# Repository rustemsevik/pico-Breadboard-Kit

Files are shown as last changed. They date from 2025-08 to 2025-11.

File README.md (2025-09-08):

# Pico Breadboard Kit

This is a Raspberry Pi Pico breadboard kit designed for students to learn and experiment with basic electronics and microcontroller programming.

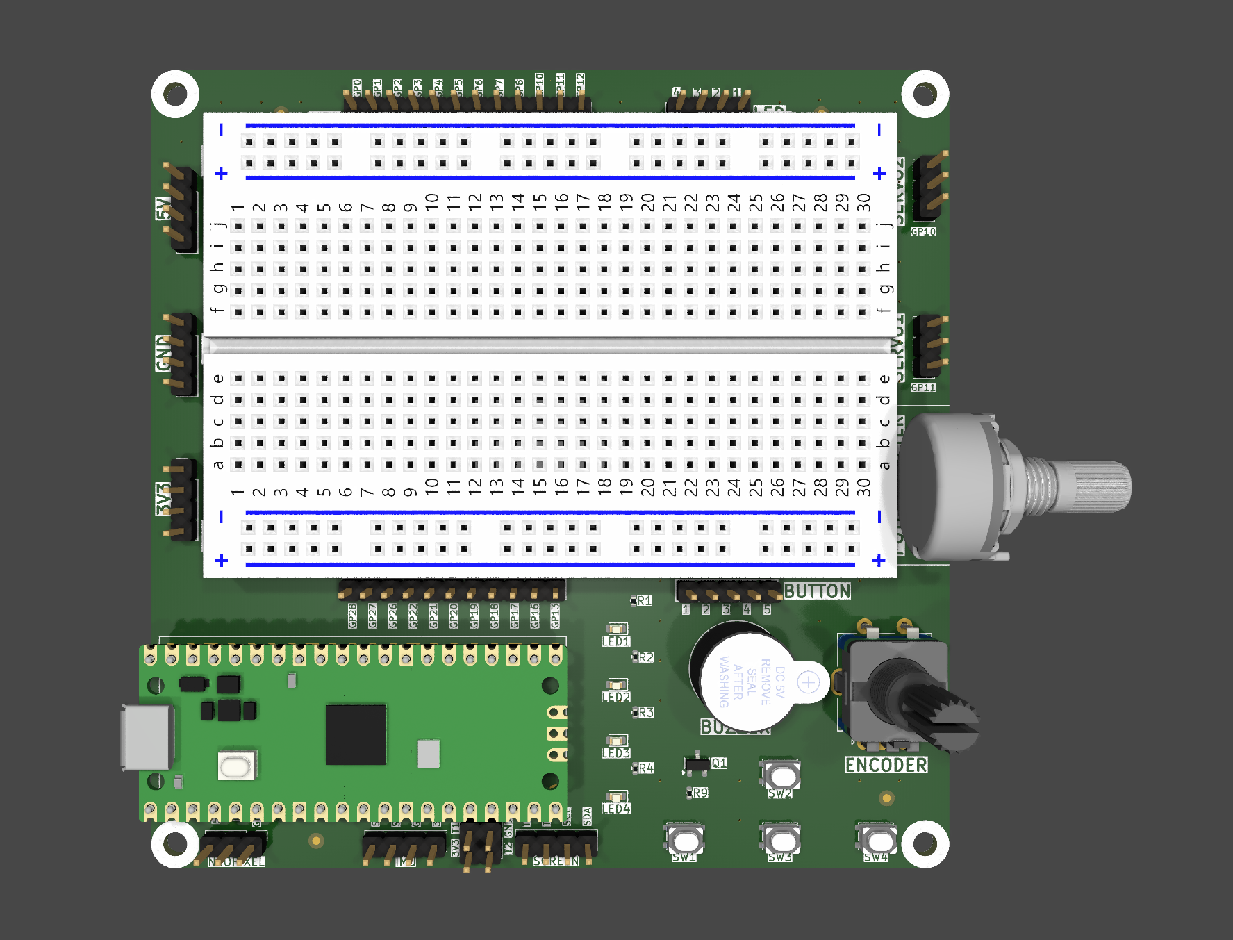
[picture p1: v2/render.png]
Pico Breadboard


## Features

- **Raspberry Pi Pico** with full GPIO breakout  
- **Four tactile buttons** connected to GPIOs  
- **Four LEDs** with current-limiting resistors  
- **Buzzer** controlled via transistor switch  
- **Rotary encoder with push switch** for interactive input  
- **Potentiometer** connected to ADC input  
- **Headers for external 3.3V and 5V power**  
- **Dedicated I2C connector for screen (SCL/SDA)**  
- **Connector for MPU6050 (I2C accelerometer/gyroscope)**  
- **Servo motor headers (2x) with GPIO control**  
- **Neopixel header** for addressable LED strips  
- Mounting holes for mechanical stability  
- All components are laid out to be easily accessible on a standard breadboard.

## Getting Started

1. Insert the Raspberry Pi Pico into the breadboard.  
2. Connect power via USB.  
3. Upload your code using Thonny or the Pico SDK.  
4. Use the built-in components (buttons, LEDs, buzzer, potentiometer, rotary encoder, servos) to test your logic.  
5. Connect external devices (screen, MPU6050, Neopixel) via the dedicated headers.  

## Schematic

See the included [`v2/pico-breadboard.pdf`](v2/pico-breadboard.pdf) for the detailed wiring.

---

This kit is ideal for beginner to intermediate-level microcontroller projects, robotics experiments, and educational settings.

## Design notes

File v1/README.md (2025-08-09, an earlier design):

# Pico Breadboard Kit

This is a simple Raspberry Pi Pico breadboard kit designed for students to learn and experiment with basic electronics and microcontroller programming.

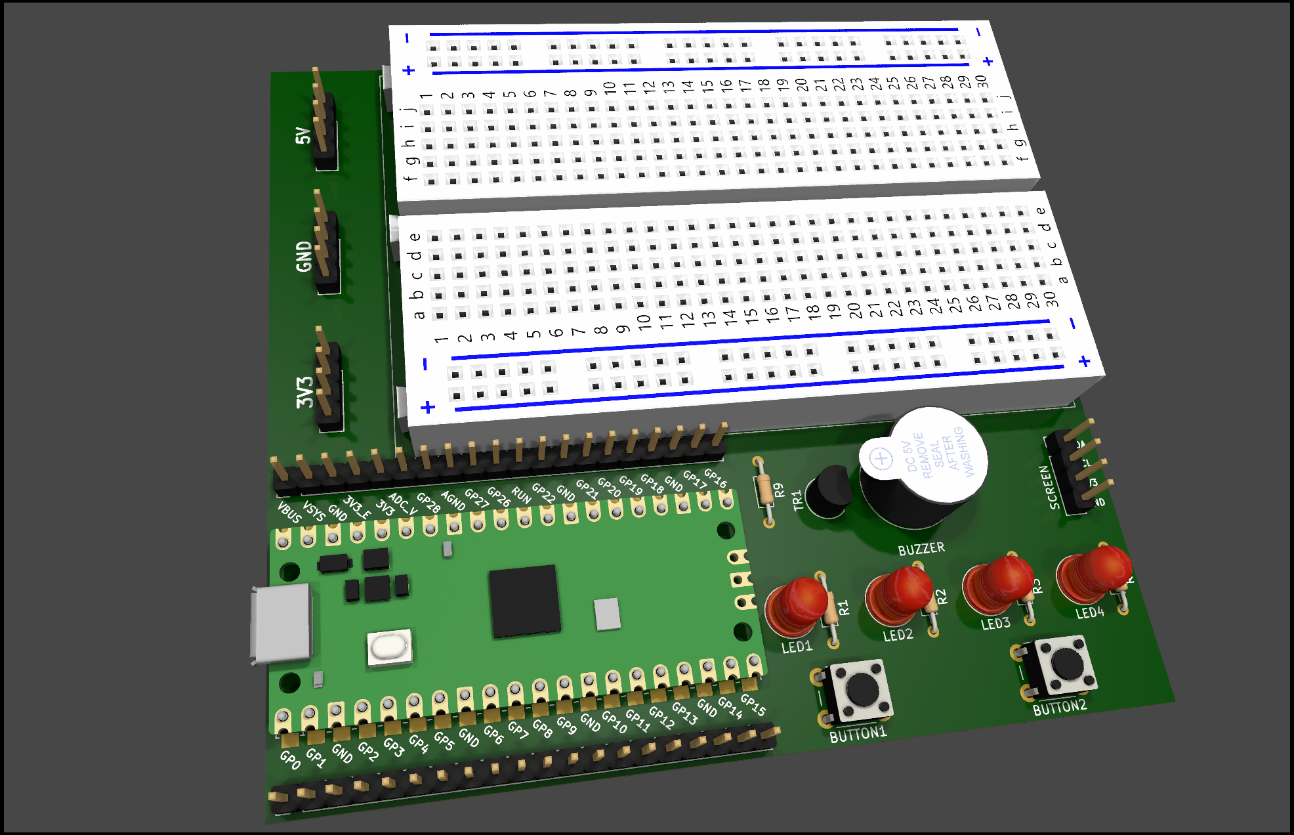
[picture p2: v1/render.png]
Pico Breadboard


## Features

- **Raspberry Pi Pico** with full GPIO breakout
- **Two tactile buttons** connected to GPIOs
- **Four LEDs** with current-limiting resistors
- **Buzzer** controlled via transistor switch
- **Headers for external 3.3V and 5V power**
- **Dedicated I2C connector for screen (SCL/SDA)**
- All components are laid out to be easily accessible on a standard breadboard.

## Getting Started

1. Insert the Raspberry Pi Pico into the breadboard.
2. Connect power via USB.
3. Upload your code using Thonny or the Pico SDK.
4. Use the built-in components (buttons, LEDs, buzzer) to test your logic.

## Schematic

See the included `schematic.pdf` for the detailed wiring.

---

This kit is ideal for beginner-level microcontroller projects and educational settings.

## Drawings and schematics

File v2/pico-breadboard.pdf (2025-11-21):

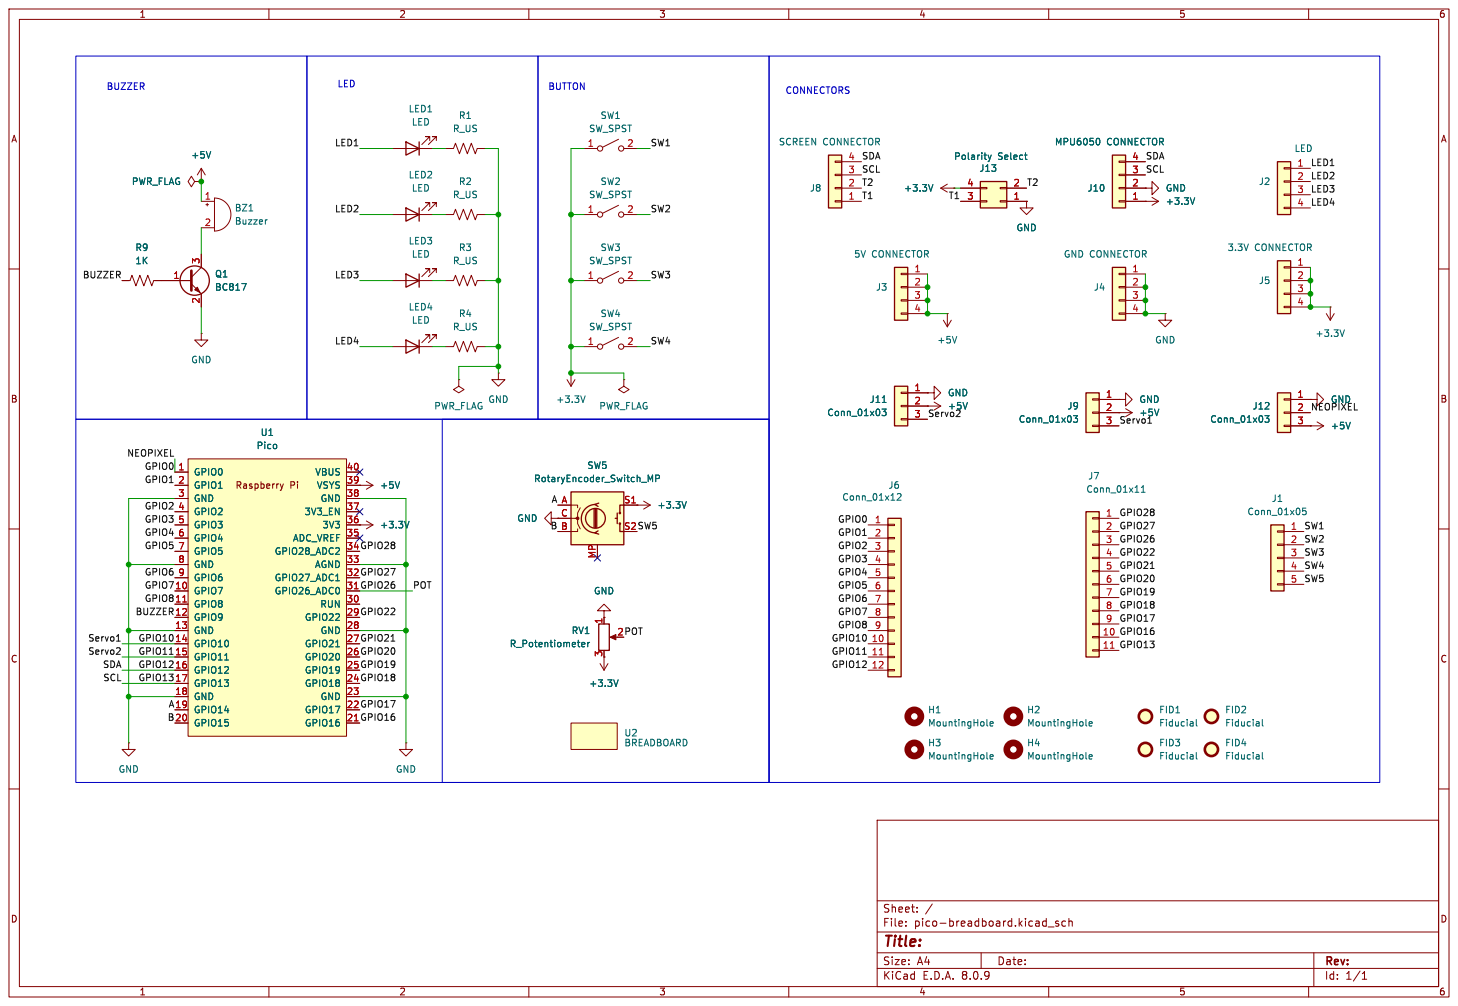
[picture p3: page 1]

3 U1 Pico GPIO0 1 GPIO7 10 GPIO8 11 GPIO9 12 GND 13 GPIO10 14 GPIO11 15 GPIO12 16 GPIO13 17 GND 18 GPIO14 19 GPIO1 2 GPIO15 20 GPIO16 21 GPIO17 22 GND 23 GPIO18 24 GPIO19 25 GPIO20 26 GPIO21 27 GND 28 GPIO22 29 GND 3 RUN 30 GPIO26_ADC0 31 GPIO27_ADC1 32 AGND 33 GPIO28_ADC2 34 ADC_VREF 35

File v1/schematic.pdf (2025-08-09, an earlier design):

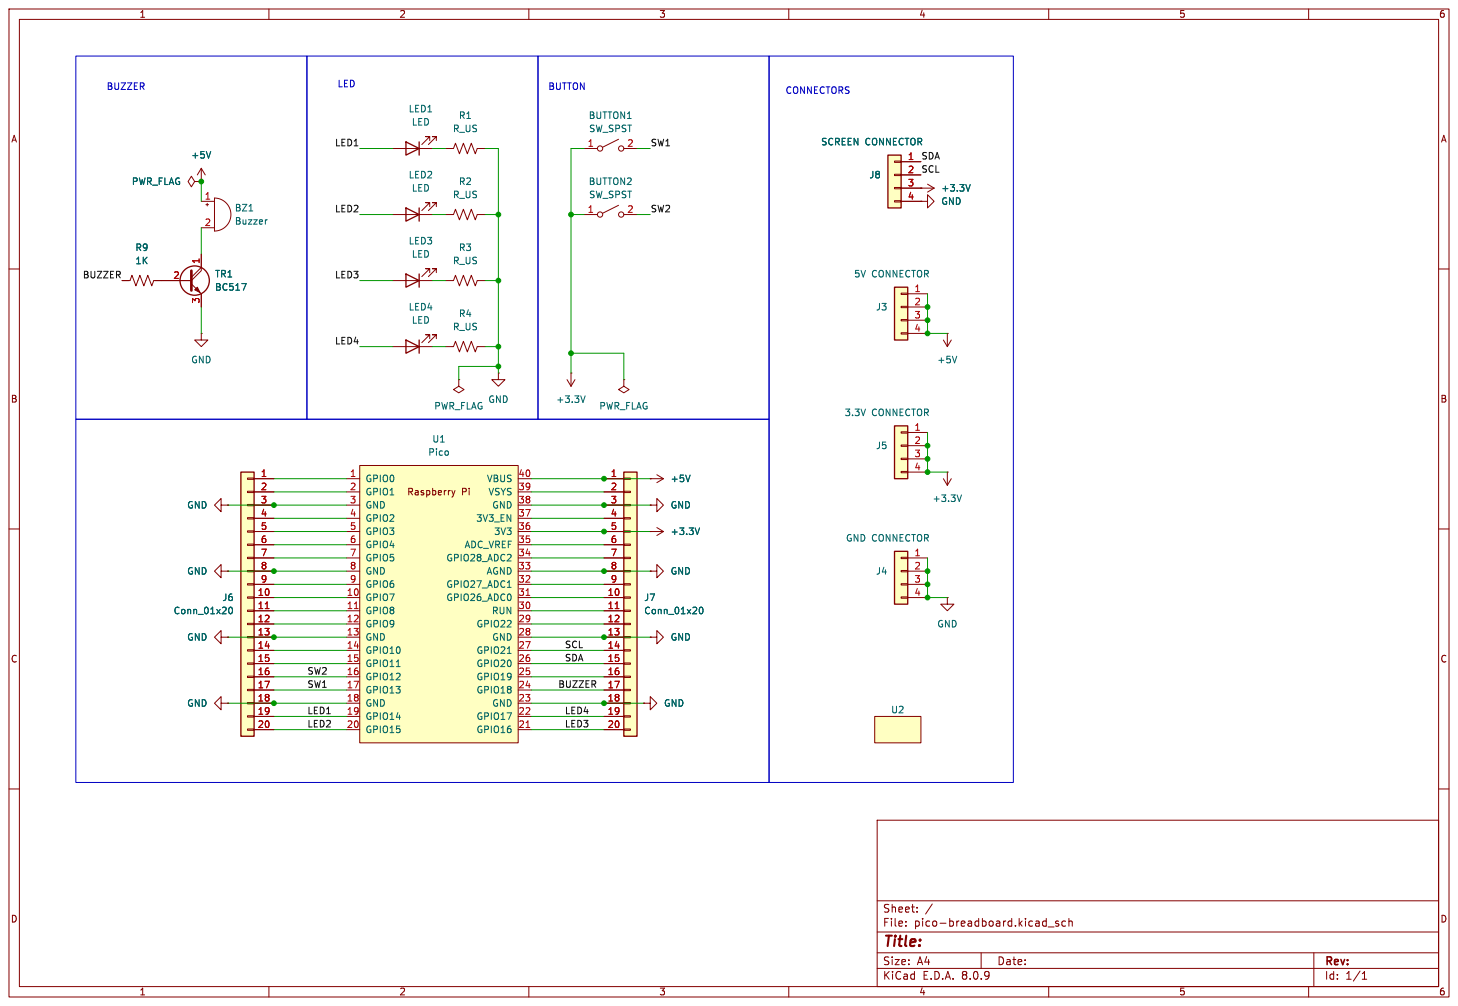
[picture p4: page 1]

203456789 GND GND GND GND

J4 GND CONNECTOR +3.3V GND GND GND

Id: 1/1 Title: File: pico-breadboard.kicad_sch Sheet: /

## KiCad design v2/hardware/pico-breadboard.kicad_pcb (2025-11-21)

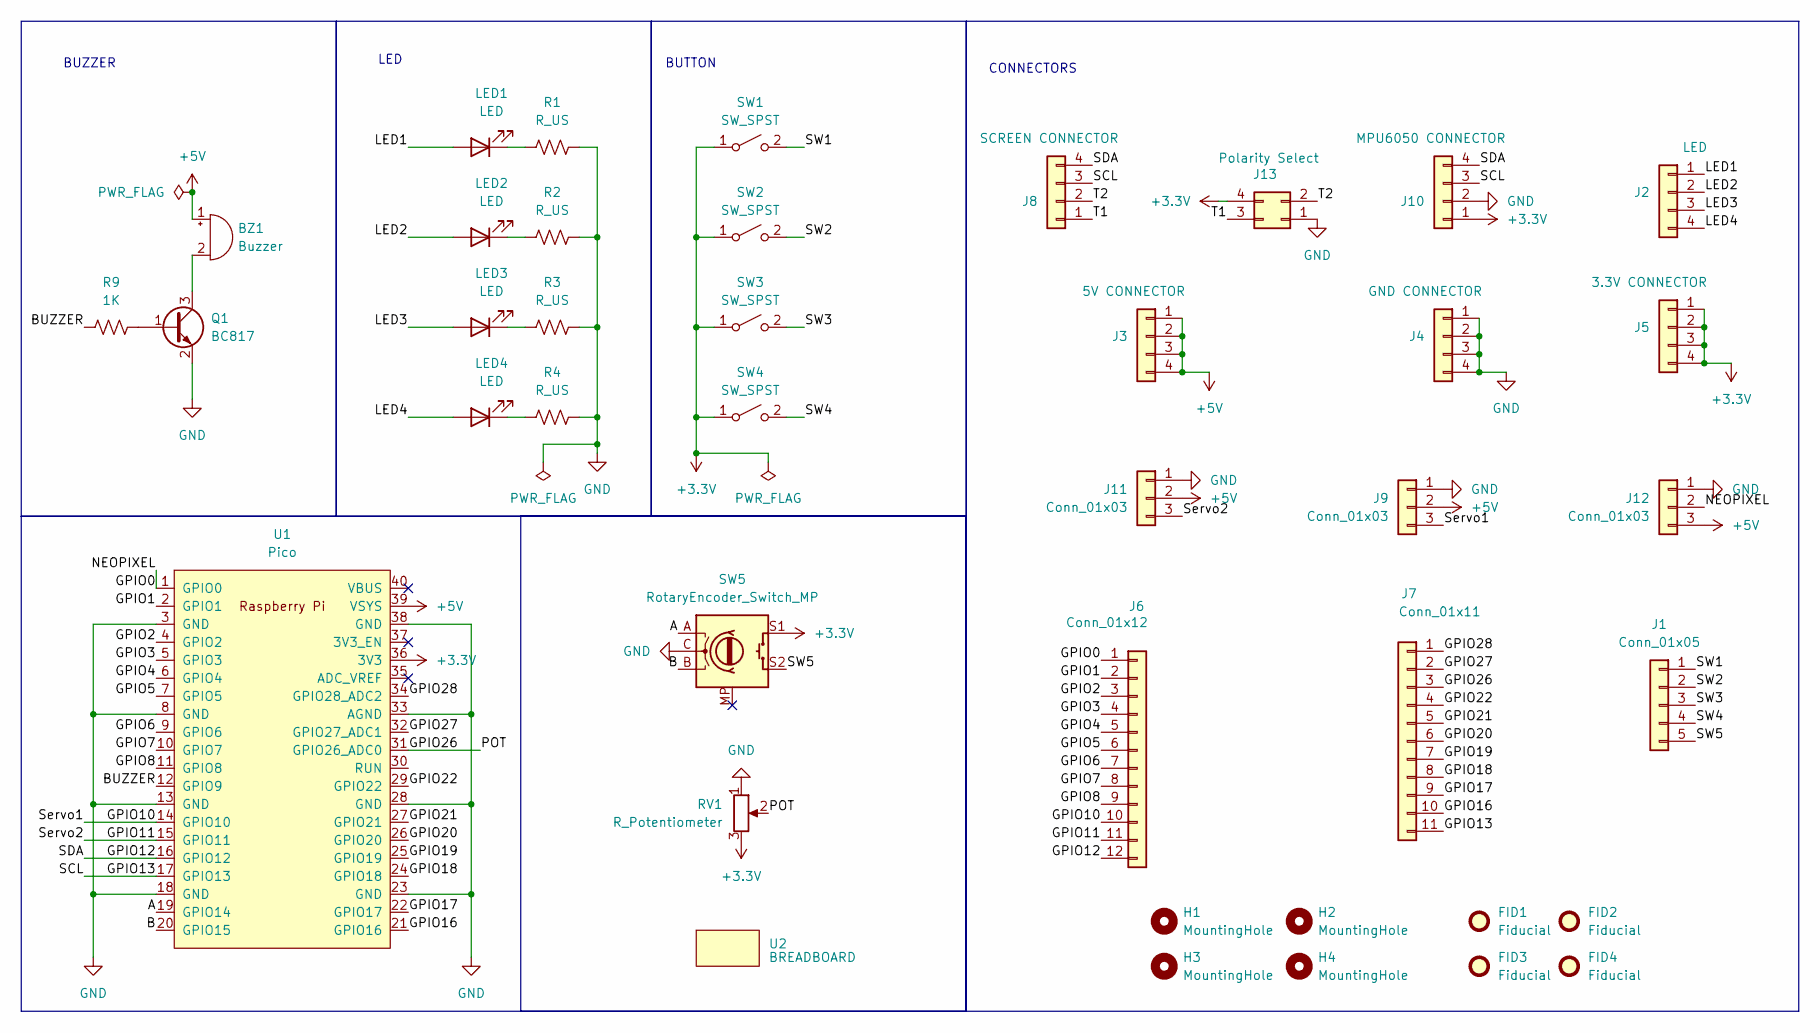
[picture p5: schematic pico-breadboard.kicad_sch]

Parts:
BZ1: Buzzer; Buzzer_12mm7.6
FID1, FID2, FID3, FID4: Fiducial; Fiducial_1mm_Mask2mm
H1, H2, H3, H4: MountingHole; MountingHole_3mm
J1: Conn_01x05; PinHeader_1x05_P2.54mm_Vertical
J2: LED; PinHeader_1x04_P2.54mm_Vertical
J3: 5V CONNECTOR; PinHeader_1x04_P2.54mm_Vertical
J4: GND CONNECTOR; PinHeader_1x04_P2.54mm_Vertical
J5: 3.3V CONNECTOR; PinHeader_1x04_P2.54mm_Vertical
J6: Conn_01x12; PinHeader_1x12_P2.54mm_Vertical
J7: Conn_01x11; PinHeader_1x11_P2.54mm_Vertical
J8: SCREEN CONNECTOR; PinHeader_1x04_P2.54mm_Vertical
J9, J11, J12: Conn_01x03; PinHeader_1x03_P2.54mm_Vertical
J10: MPU6050 CONNECTOR; PinHeader_1x04_P2.54mm_Vertical
J13: Polarity Select; PinHeader_2x02_P2.54mm_Vertical
LED1, LED2, LED3, LED4: LED; LED_0603_1608Metric
Q1: BC817; SOT-23
R1, R2, R3, R4: R_US; R_0402_1005Metric
R9: 1K; R_0402_1005Metric
RV1: R_Potentiometer; Potentiometer_Omeg_PC16BU_Horizontal
SW1, SW2, SW3, SW4: SW_SPST; SW_SPST_PTS810
SW5: RotaryEncoder_Switch_MP; RotaryEncoder_Alps_EC11E-Switch_Vertical_H20mm
U1: Pico; RPi_Pico_SMD_TH
U2: BREADBOARD; Breadboard

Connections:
+3.3V: J5.1, J5.2, J5.3, J5.4, J10.1, J13.4, RV1.3, SW1.1 (A), SW2.1 (A), SW3.1 (A), SW4.1 (A), SW5.S1, U1.36 (3V3)
+5V: BZ1.1 (+), J3.1, J3.2, J3.3, J3.4, J9.2, J11.2, J12.3, U1.39 (VSYS)
/A: SW5.A, U1.19 (GPIO14)
/B: SW5.B, U1.20 (GPIO15)
/BUZZER: R9.1, U1.12 (GPIO9)
/GPIO0: J6.1, J12.2, U1.1 (GPIO0)
/GPIO1: J6.2, U1.2 (GPIO1)
/GPIO2: J6.3, U1.4 (GPIO2)
/GPIO3: J6.4, U1.5 (GPIO3)
/GPIO4: J6.5, U1.6 (GPIO4)
/GPIO5: J6.6, U1.7 (GPIO5)
/GPIO6: J6.7, U1.9 (GPIO6)
/GPIO7: J6.8, U1.10 (GPIO7)
/GPIO8: J6.9, U1.11 (GPIO8)
/GPIO10: J6.10, J9.3, U1.14 (GPIO10)
/GPIO11: J6.11, J11.3, U1.15 (GPIO11)
/GPIO12: J6.12, J8.4, J10.4, U1.16 (GPIO12)
/GPIO13: J7.11, J8.3, J10.3, U1.17 (GPIO13)
/GPIO16: J7.10, U1.21 (GPIO16)
/GPIO17: J7.9, U1.22 (GPIO17)
/GPIO18: J7.8, U1.24 (GPIO18)
/GPIO19: J7.7, U1.25 (GPIO19)
/GPIO20: J7.6, U1.26 (GPIO20)
/GPIO21: J7.5, U1.27 (GPIO21)
/GPIO22: J7.4, U1.29 (GPIO22)
/GPIO26: J7.3, RV1.2, U1.31 (GPIO26_ADC0)
/GPIO27: J7.2, U1.32 (GPIO27_ADC1)
/GPIO28: J7.1, U1.34 (GPIO28_ADC2)
/LED1: J2.1, LED1.2 (A)
/LED2: J2.2, LED2.2 (A)
/LED3: J2.3, LED3.2 (A)
/LED4: J2.4, LED4.2 (A)
/SW1: J1.1, SW1.2 (B)
/SW2: J1.2, SW2.2 (B)
/SW3: J1.3, SW3.2 (B)
/SW4: J1.4, SW4.2 (B)
/SW5: J1.5, SW5.S2
/T1: J8.1, J13.3
/T2: J8.2, J13.2
GND: J4.1, J4.2, J4.3, J4.4, J9.1, J10.2, J11.1, J12.1, J13.1, Q1.2 (E), R1.2, R2.2, R3.2, R4.2, RV1.1, SW5.C, U1.3 (GND), U1.8 (GND), U1.13 (GND), U1.18 (GND), U1.23 (GND), U1.28 (GND), U1.33 (AGND), U1.38 (GND)
unnamed: BZ1.2 (-), Q1.3 (C)
unnamed: LED1.1 (K), R1.1
unnamed: LED2.1 (K), R2.1
unnamed: LED3.1 (K), R3.1
unnamed: LED4.1 (K), R4.1
unnamed: Q1.1 (B), R9.2

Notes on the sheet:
BUTTON
CONNECTORS
LED
BUZZER

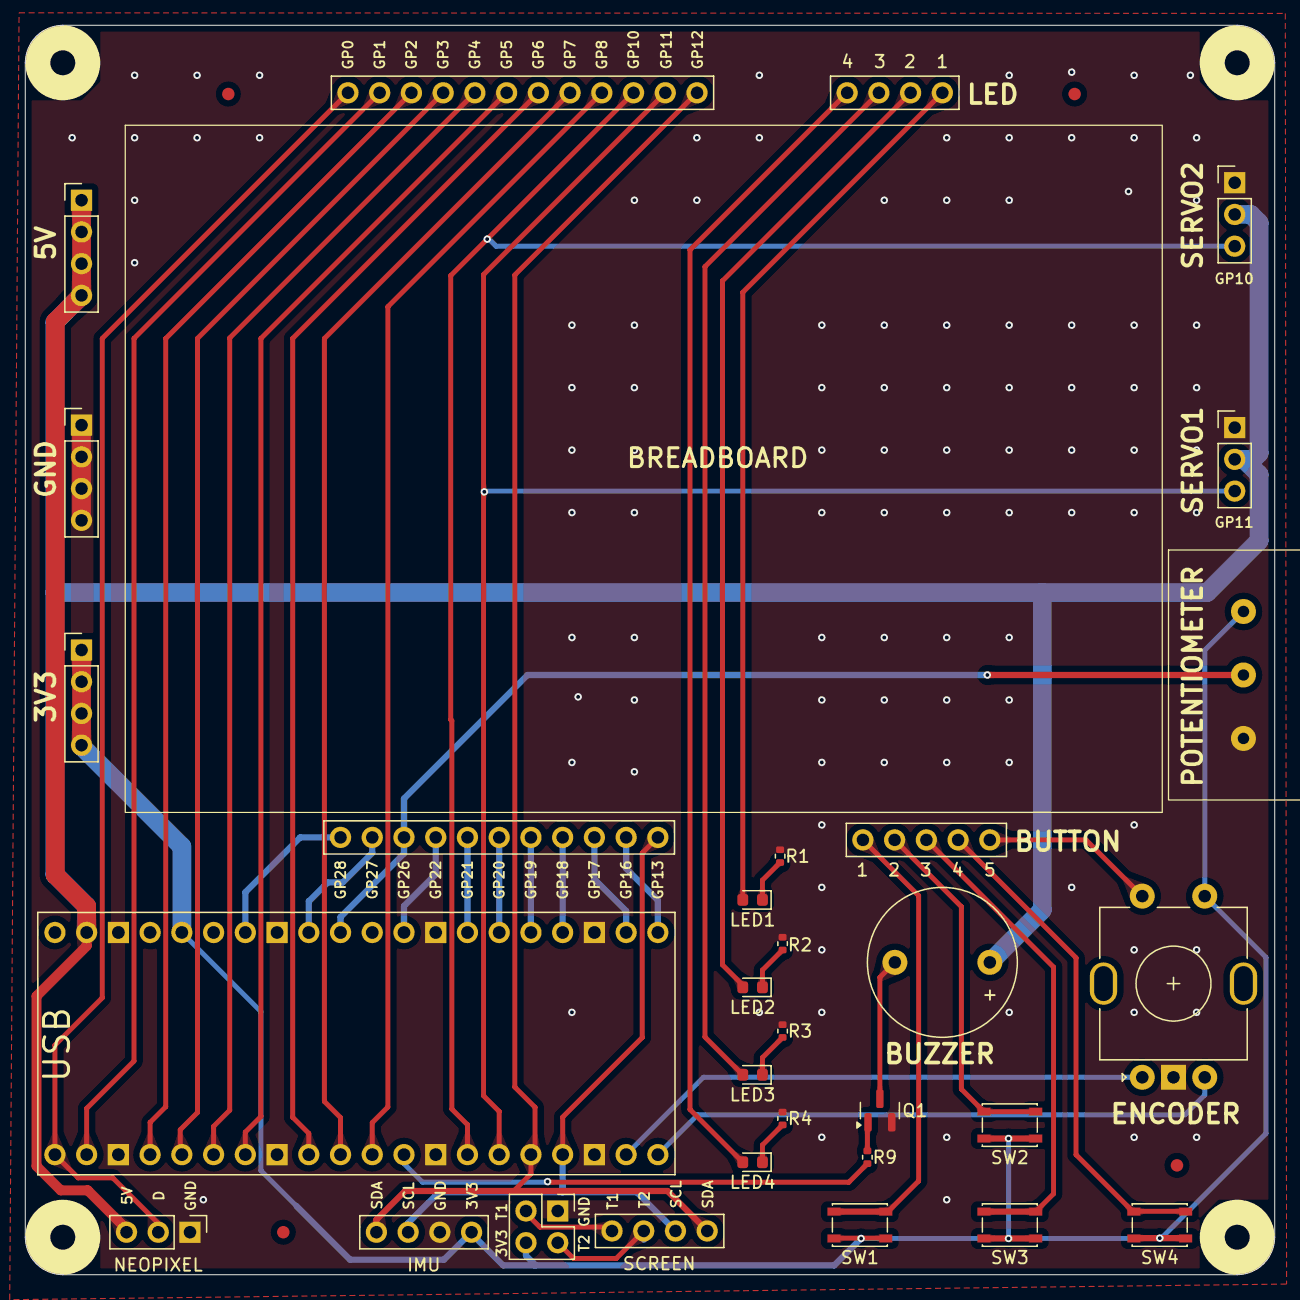
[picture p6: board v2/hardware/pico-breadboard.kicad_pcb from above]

Board: 2 copper layers, 100.0 x 100.0 mm, 40 parts (1 on the bottom side), 46 nets.

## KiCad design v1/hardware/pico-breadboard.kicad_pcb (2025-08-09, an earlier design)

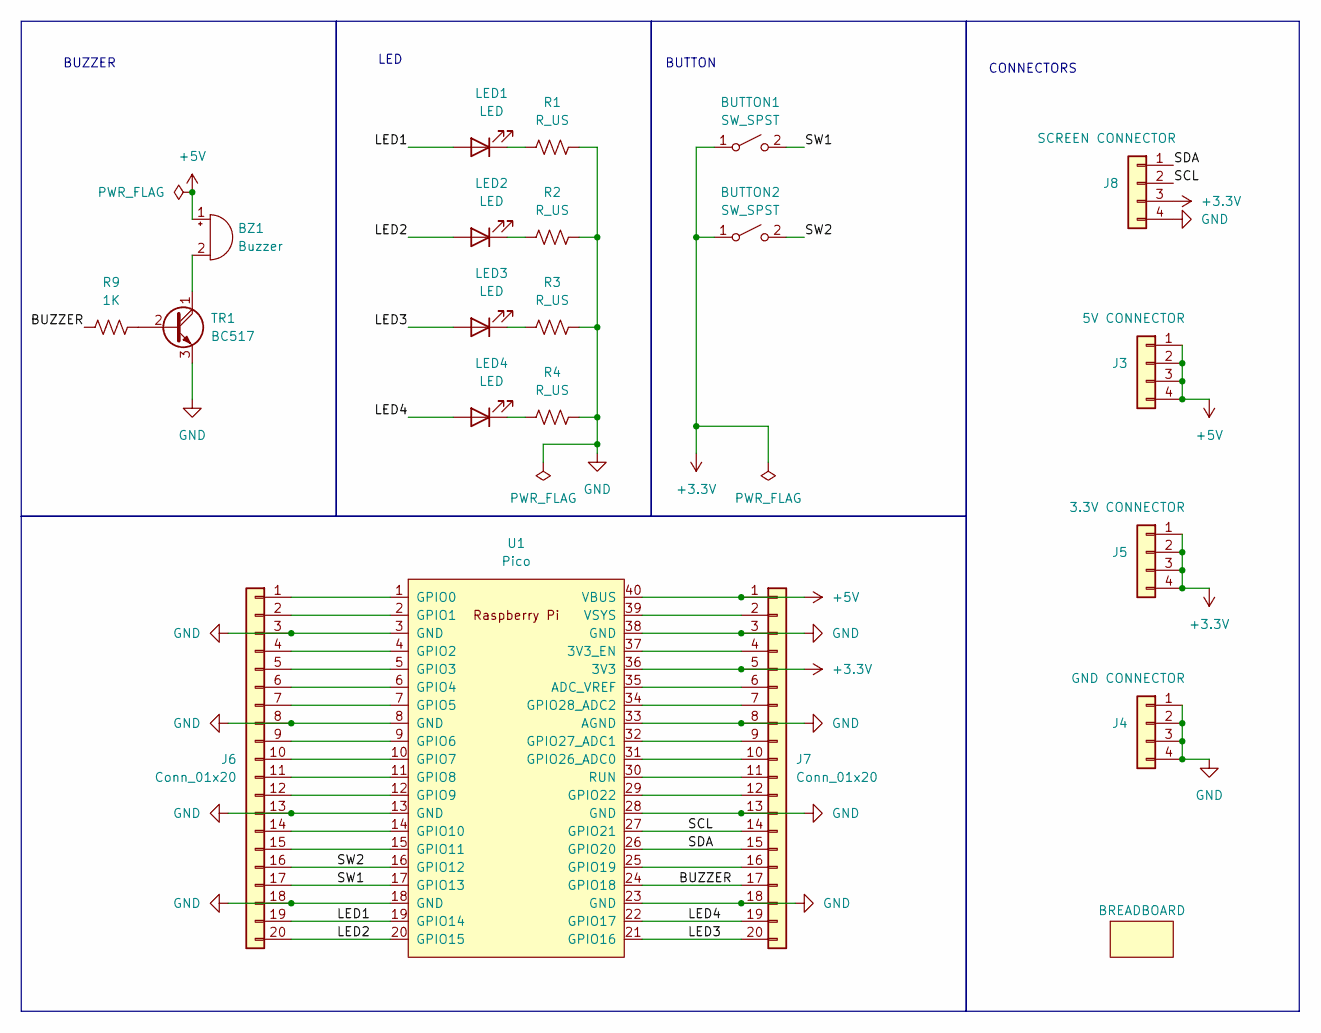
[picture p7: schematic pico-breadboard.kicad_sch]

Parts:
BREADBOARD: Breadboard
BUTTON1, BUTTON2: SW_SPST; SW_PUSH_6mm
BZ1: Buzzer; Buzzer_15x7.5RM7.6
J3: 5V CONNECTOR; PinHeader_1x04_P2.54mm_Vertical
J4: GND CONNECTOR; PinHeader_1x04_P2.54mm_Vertical
J5: 3.3V CONNECTOR; PinHeader_1x04_P2.54mm_Vertical
J6, J7: Conn_01x20; PinHeader_1x20_P2.54mm_Vertical
J8: SCREEN CONNECTOR; PinHeader_1x04_P2.54mm_Vertical
LED1, LED2, LED3, LED4: LED; LED_D5.0mm
R1, R2, R3, R4: R_US; R_Axial_DIN0204_L3.6mm_D1.6mm_P7.62mm_Horizontal
R9: 1K; R_Axial_DIN0204_L3.6mm_D1.6mm_P7.62mm_Horizontal
TR1: BC517; TO-92_Inline
U1: Pico; RPi_Pico_SMD_TH

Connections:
+3.3V: BUTTON1.1 (A), BUTTON2.1 (A), J5.1, J5.2, J5.3, J5.4, J7.5, J8.3, U1.36 (3V3)
+5V: BZ1.1 (+), J3.1, J3.2, J3.3, J3.4, J7.1, U1.40 (VBUS)
/BUZZER: J7.17, R9.1, U1.24 (GPIO18)
/LED1: J6.19, LED1.2 (A), U1.19 (GPIO14)
/LED2: J6.20, LED2.2 (A), U1.20 (GPIO15)
/LED3: J7.20, LED3.2 (A), U1.21 (GPIO16)
/LED4: J7.19, LED4.2 (A), U1.22 (GPIO17)
/SCL: J7.14, J8.2, U1.27 (GPIO21)
/SDA: J7.15, J8.1, U1.26 (GPIO20)
/SW1: BUTTON1.2 (B), J6.17, U1.17 (GPIO13)
/SW2: BUTTON2.2 (B), J6.16, U1.16 (GPIO12)
GND: J4.1, J4.2, J4.3, J4.4, J6.3, J6.8, J6.13, J6.18, J7.3, J7.8, J7.13, J7.18, J8.4, R1.2, R2.2, R3.2, R4.2, TR1.3 (E), U1.3 (GND), U1.8 (GND), U1.13 (GND), U1.18 (GND), U1.23 (GND), U1.28 (GND), U1.33 (AGND), U1.38 (GND)
unnamed: BZ1.2 (-), TR1.1 (C)
unnamed: J6.1, U1.1 (GPIO0)
unnamed: J6.2, U1.2 (GPIO1)
unnamed: J6.4, U1.4 (GPIO2)
unnamed: J6.5, U1.5 (GPIO3)
unnamed: J6.6, U1.6 (GPIO4)
unnamed: J6.7, U1.7 (GPIO5)
unnamed: J6.9, U1.9 (GPIO6)
unnamed: J6.10, U1.10 (GPIO7)
unnamed: J6.11, U1.11 (GPIO8)
unnamed: J6.12, U1.12 (GPIO9)
unnamed: J6.14, U1.14 (GPIO10)
unnamed: J6.15, U1.15 (GPIO11)
unnamed: J7.2, U1.39 (VSYS)
unnamed: J7.4, U1.37 (3V3_EN)
unnamed: J7.6, U1.35 (ADC_VREF)
unnamed: J7.7, U1.34 (GPIO28_ADC2)
unnamed: J7.9, U1.32 (GPIO27_ADC1)
unnamed: J7.10, U1.31 (GPIO26_ADC0)
unnamed: J7.11, U1.30 (RUN)
unnamed: J7.12, U1.29 (GPIO22)
unnamed: J7.16, U1.25 (GPIO19)
unnamed: LED1.1 (K), R1.1
unnamed: LED2.1 (K), R2.1
unnamed: LED3.1 (K), R3.1
unnamed: LED4.1 (K), R4.1
unnamed: R9.2, TR1.2 (B)

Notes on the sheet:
BUTTON
CONNECTORS
LED
BUZZER

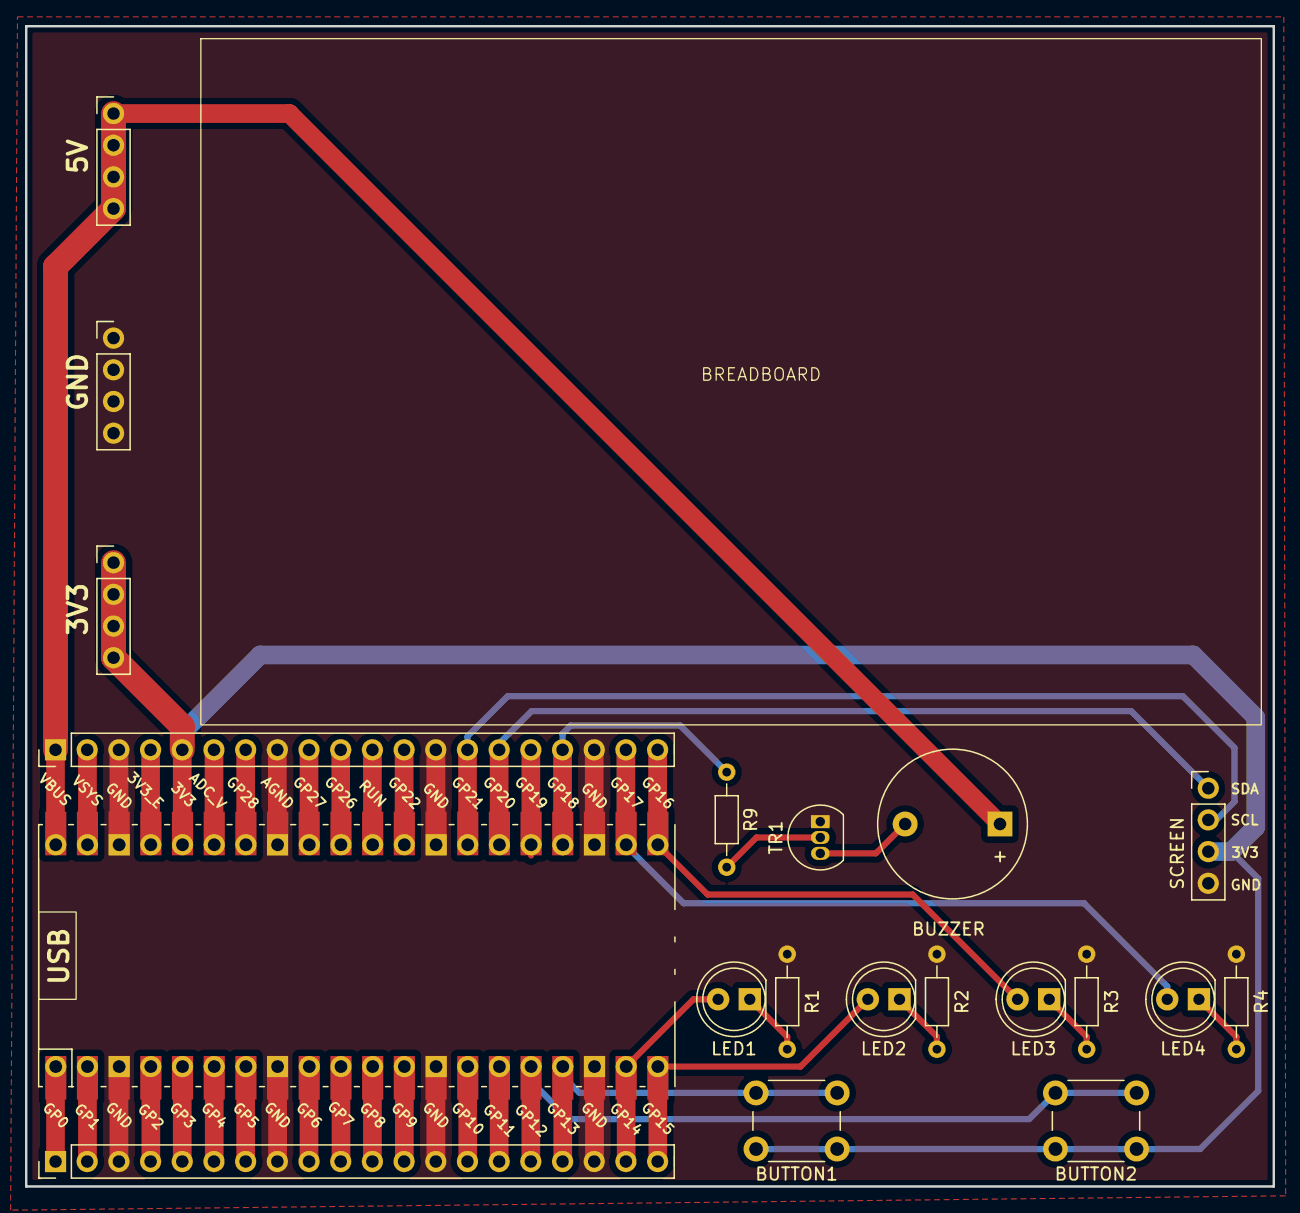
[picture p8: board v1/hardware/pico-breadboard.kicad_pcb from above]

Board: 2 copper layers, 100.0 x 93.0 mm, 21 parts (0 on the bottom side), 39 nets.

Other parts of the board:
U2: Breadboard

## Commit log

2025-08-09 Add KiCad .gitignore
2025-08-09 schematic updated
2025-08-09 minor changes
    [pico-breadboard.kicad_sch]
2025-08-11 v2 created
    [pico-breadboard.kicad_pcb, pico-breadboard.kicad_sch]
2025-09-08 v2 updated
    [pico-breadboard.kicad_pcb, pico-breadboard.kicad_sch]
2025-10-19 silkscreen fixel board size adjusted
    [pico-breadboard.kicad_pcb]
2025-11-21 polarity selector added
    [pico-breadboard.kicad_pcb]
